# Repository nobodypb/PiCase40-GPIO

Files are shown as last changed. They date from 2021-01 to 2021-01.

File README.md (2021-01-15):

# PiCase40-GPIO

Fixing the GPIO rows order of Cooler Masters Pi Case 40.
KiCAD project for custom header pcb in `PiHeader`.

**NOT FULLY TESTED YET!**

## Guide for fixing with custom made ribbon cable

This is intended as fix **instead** of a custom PCB, so please don't try to combine both.

Overall you *only* need to get two things and stick them together:

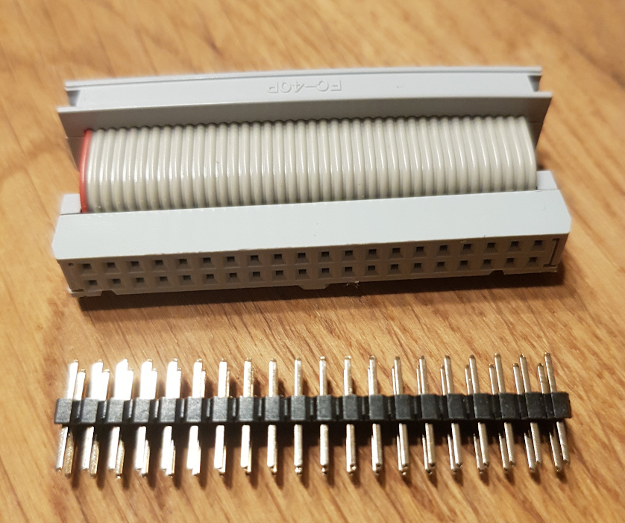
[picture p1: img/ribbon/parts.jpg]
Parts for custom cable fix


On the top you see basically a plain female to female ribbon cable. Such are also often used for the RasPi T-Cobbler.
This specific version I've made myself to arrange the connectors on opposite sides and make it as short as possible, but a longer cable with connectors on the same side will also work.
Just note that the notch on the connector must be facing upwards when it is plugged into the Case40 for it to fit. So get a cable with one notch faced like below.

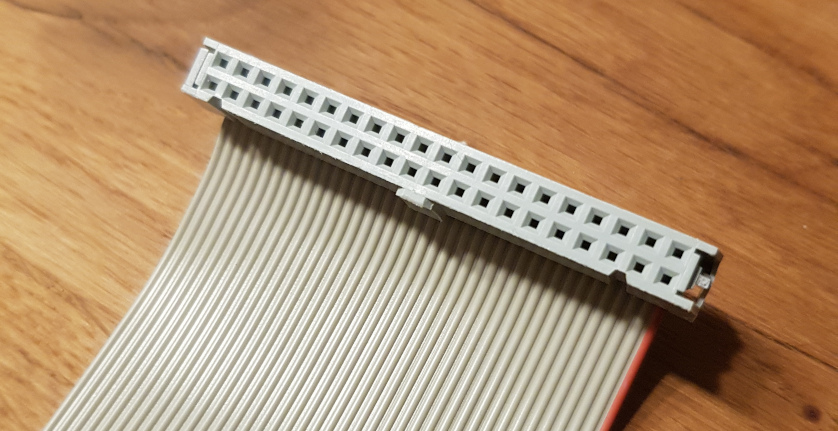
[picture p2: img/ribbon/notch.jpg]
Notch direction


The second part you need is a male to male pinheader with (equally) **long pins on both sides**. Those pins should be at least 5.7mm in length on both sides. Spacing is 2.54mm and ofcourse you need 2x20 pins.
That sounds pretty simple, but as I discovered, it's hard to find and get. If you find distributors for this, please tell me.

A list of possible sources:
* [Aliexpress](https://www.aliexpress.com/item/33021895185.html)
* [Digikey](https://www.digikey.com/product-detail/en/sullins-connector-solutions/PRPC020DABN-RC/S2021EC-20-ND/2775919)
* [Kenable](https://www.kenable.co.uk/en/computer-cables-peripherals/ide-cables/1250-ide-pata-40-pin-40pin-coupler-adapter-male-pins-to-male-pins-001250-5055383412501.html) (also sells on amazon)
* [Schmartboard](https://schmartboard.com/qty-4-2-x-20-male-extra-long-headers-920-0198-01/)

If you fail to get one of those, try your luck on using two single row headers. Like these: [Aliexpress](https://www.aliexpress.com/item/32651418137.html)

After you managed to get those two parts you simply stick them together and one end into the header of your Pi Case40:

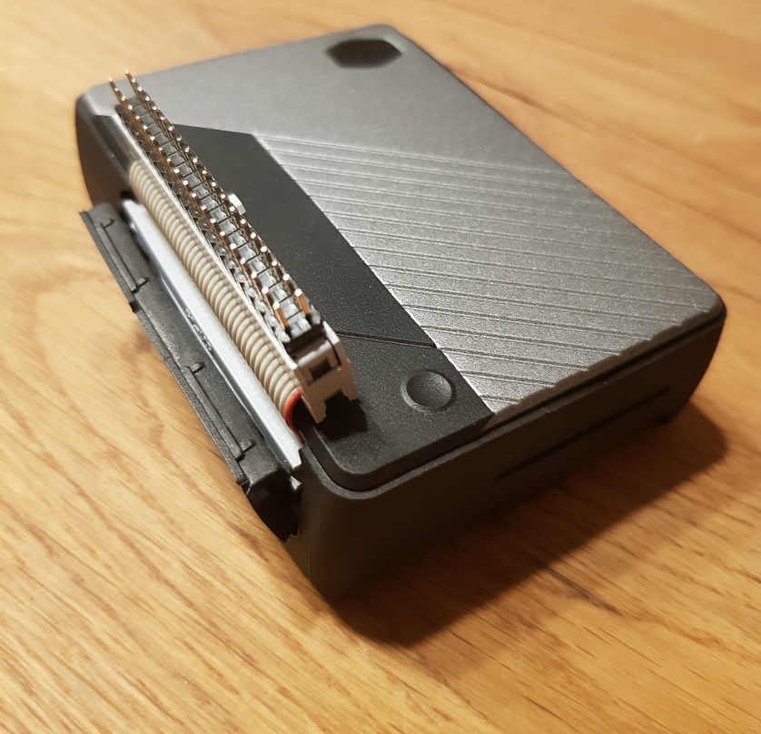
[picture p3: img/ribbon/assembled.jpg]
Assembled ribbon cable fix


Afterwards you can use yours HATs aus usual! Just make sure not to plug in the HAT the wrong way around, especially if your plugs are facing the same direction.

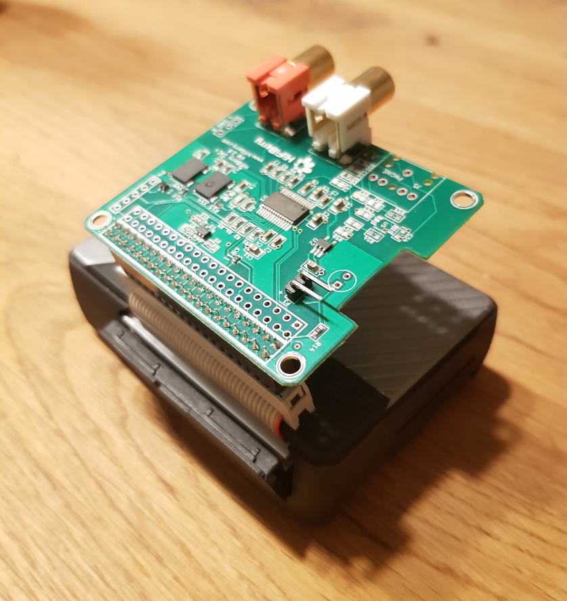
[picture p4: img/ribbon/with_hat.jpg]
Fix with connected HAT


## Quick evening update

I've recieved my ordered PCBs today and wanted to share a quick update:

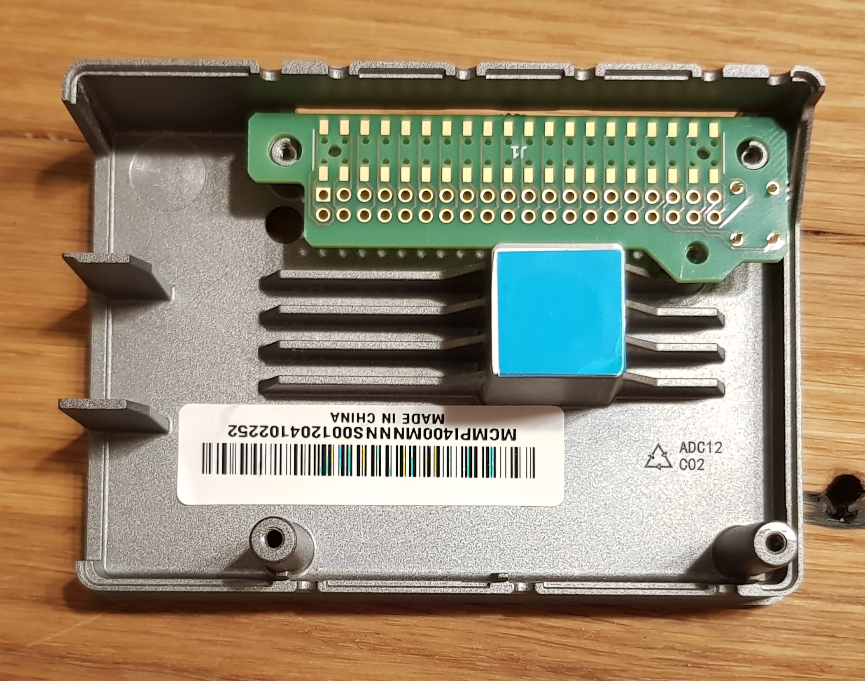
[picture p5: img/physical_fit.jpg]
Topview of PCB in case

As you can see the physical dimensions of the PCB are all correct and fit really well.

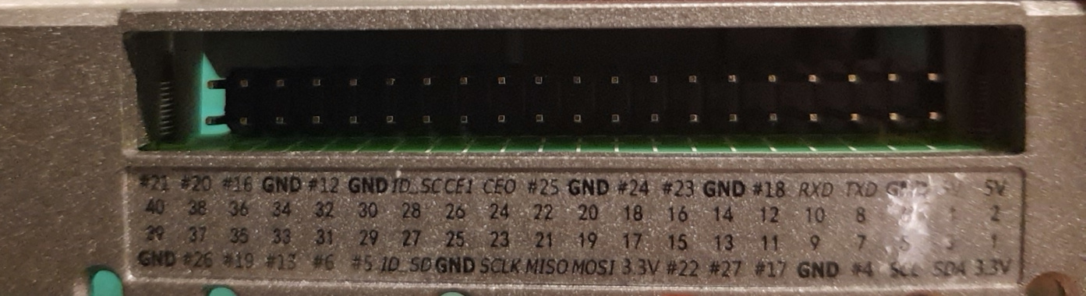
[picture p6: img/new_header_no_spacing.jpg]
Sideview of PCB with header in case

The pin header also is correct, but due to the missing spacing aligned to the bottom of the opening.
I've already successfully tested a small hack to add some spacing that worked very well and got the header to the center.
That is only applicable when assembling by hand though.

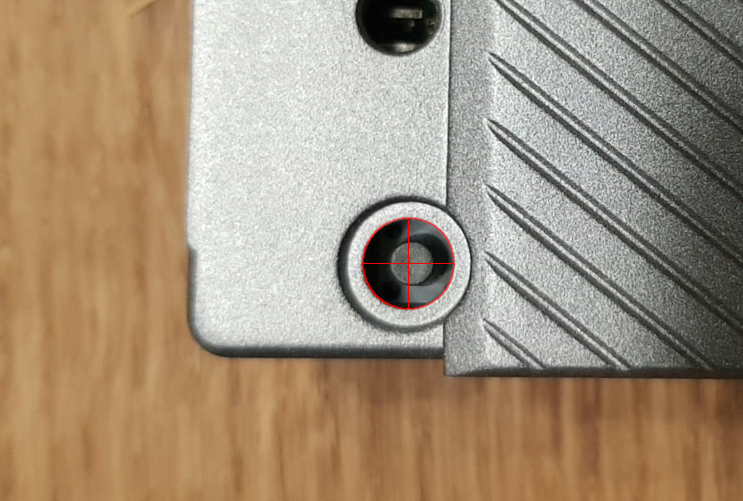
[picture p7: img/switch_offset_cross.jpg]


The button has a small offset to the right, that's something I'll fix in the layout soon. While this isn't affecting functionality there is another problem that does.
Without TPU the button works just fine, but otherwise it's to short to get pressed. That's because I didn't find one with 10.5mm in height, but used 9.6mm. Therefore here is also a spacing hack needed.
Besides that the operation force of the button I used seems to be to low. With TPU I barely get haptic feedback when pressing it. I've used `TL1105GF160Q` so I suggest to try `TL1105GF250Q` or something with an equally high actuation force.

I've soldered one version together and tried the fitting of the RasPi. In X and Y direction, there's no problem. The pin headers fit like a charm and even are easier to pull out then the original due to lower height.
Since I ordered a board with a thickness of 1.6mm for the first test, I still had to test if the cooler was in contact with the SoC. For this I used some plasticine.
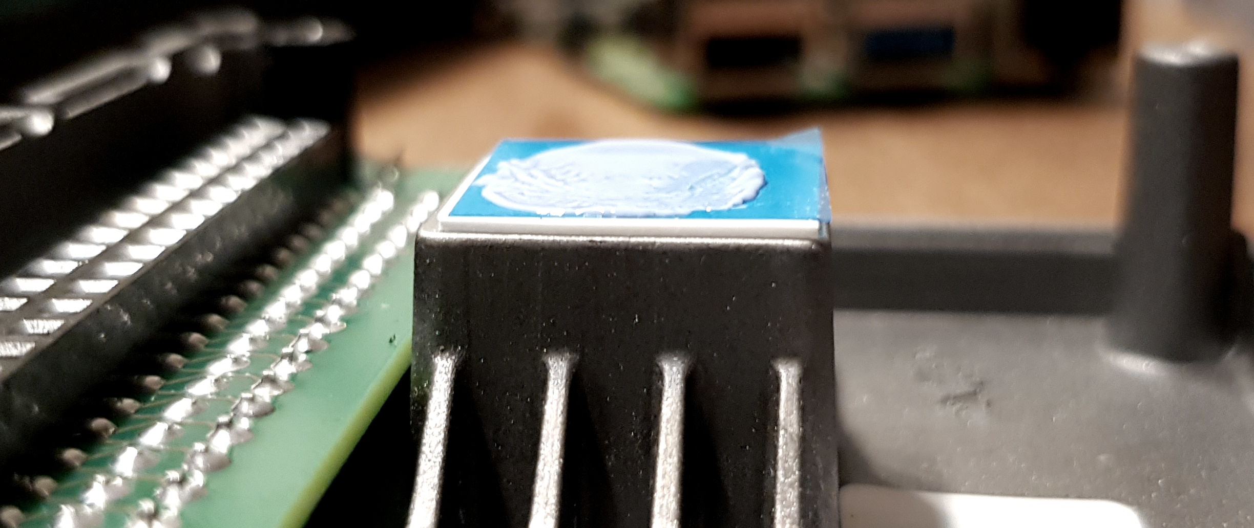
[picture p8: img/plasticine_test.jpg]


As expected, the gap is a bit higher than with the original board, but even with just one thermal pad it might still work. 
To be on the safe side, I used two pads and with those I clearly felt the back pressure. On the left side, I couldn't even tighten the screws strongly to avoid bending the board.
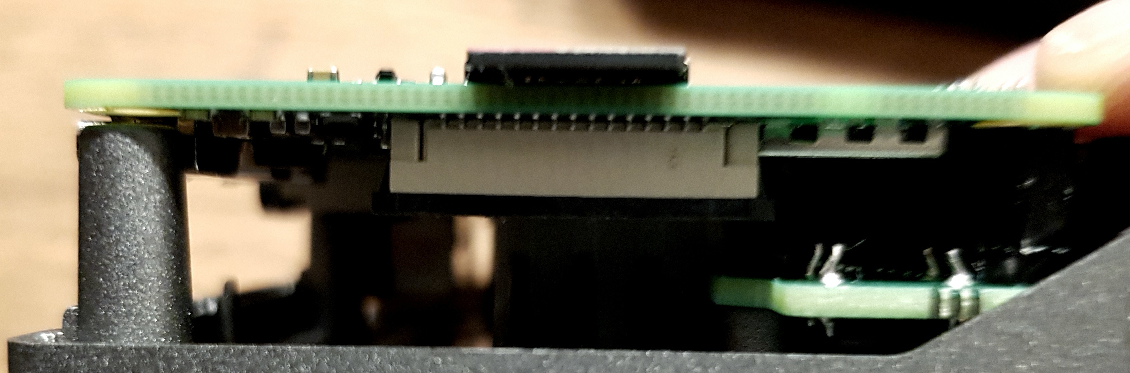
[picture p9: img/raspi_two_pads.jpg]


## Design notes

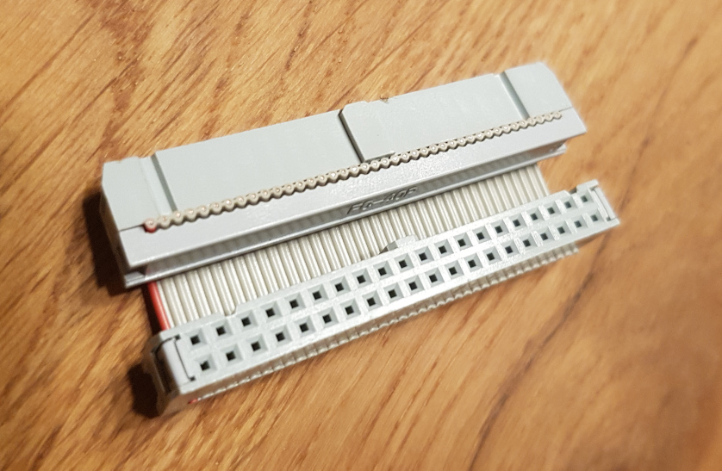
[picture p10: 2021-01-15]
img/ribbon/cable.jpg

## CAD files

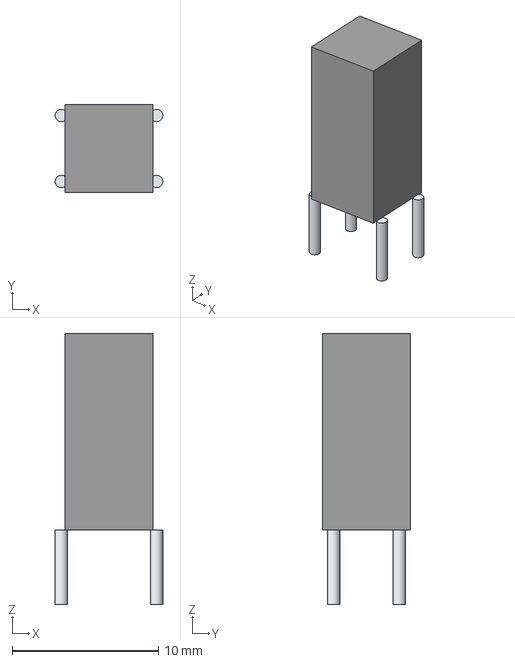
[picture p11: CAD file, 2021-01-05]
PiHeader/shapes3D/TL1105GF160Q.stp
7.35 x 6.00 x 18.5 mm
Leads x 4

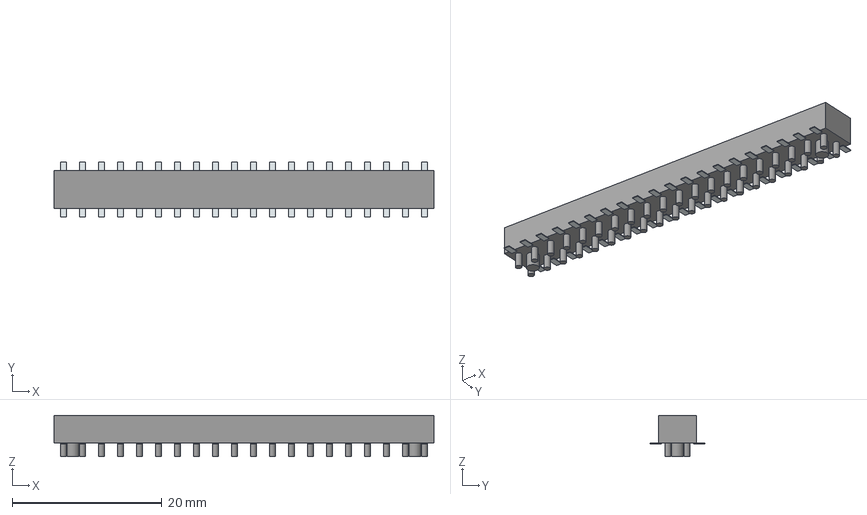
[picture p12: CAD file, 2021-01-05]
PiHeader/shapes3D/M20-7812045.stp
50.8 x 7.40 x 5.50 mm
Pins
Lugs x 42

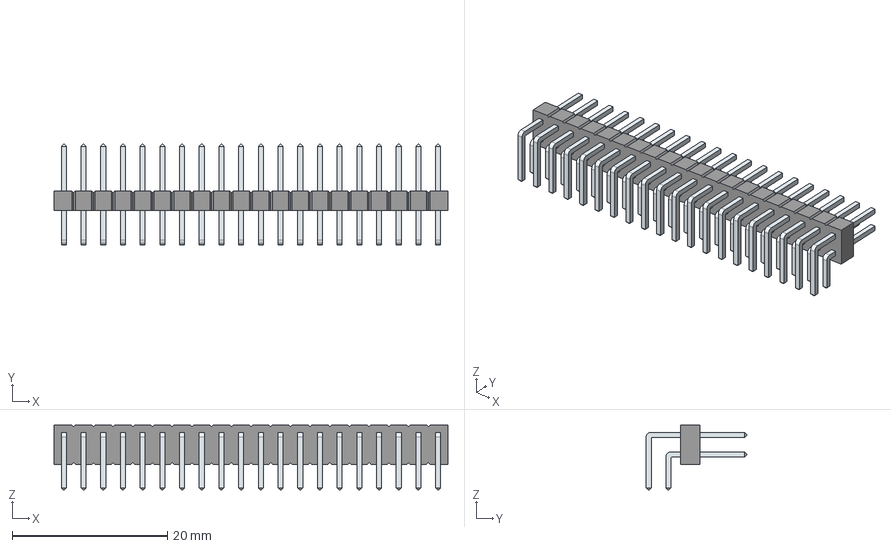
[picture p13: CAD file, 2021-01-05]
PiHeader/shapes3D/10129382-940001BLF.stp
50.8 x 13.0 x 8.38 mm
LeadsArray x 2

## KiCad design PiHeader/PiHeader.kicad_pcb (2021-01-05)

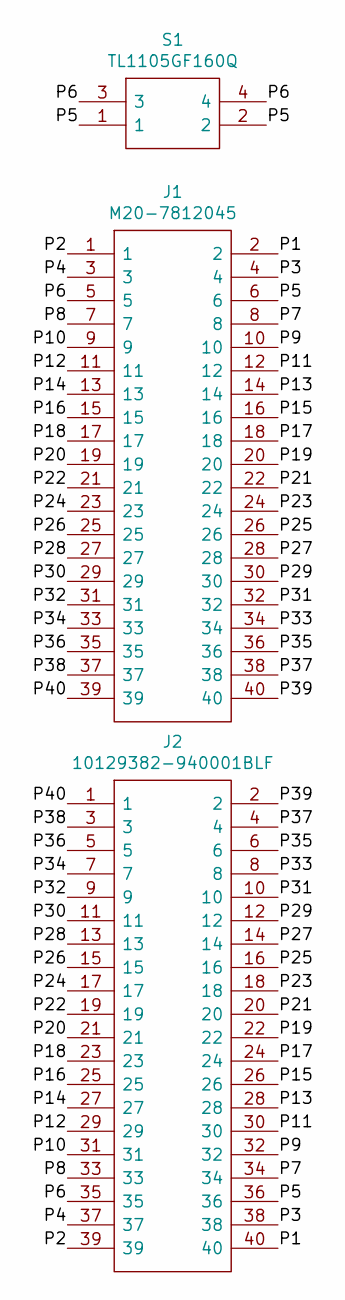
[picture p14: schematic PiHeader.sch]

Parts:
J1: M20-7812045; M207812045; Mouser Part Number 855-M20-7812045
J2: 10129382-940001BLF; HDRRA40W67P254_2X20_5080X254X508P; Manufacturer_Part_Number 10129382-940001BLF; Mouser Part Number 649-1012938294001BLF
S1: TL1105GF160Q; Mouser Part Number 612-TL1105G160Q

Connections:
/P1: J1.2, J2.40
/P2: J1.1, J2.39
/P3: J1.4, J2.38
/P4: J1.3, J2.37
/P5: J1.6, J2.36, S1.1, S1.2
/P6: J1.5, J2.35, S1.3, S1.4
/P7: J1.8, J2.34
/P8: J1.7, J2.33
/P9: J1.10, J2.32
/P10: J1.9, J2.31
/P11: J1.12, J2.30
/P12: J1.11, J2.29
/P13: J1.14, J2.28
/P14: J1.13, J2.27
/P15: J1.16, J2.26
/P16: J1.15, J2.25
/P17: J1.18, J2.24
/P18: J1.17, J2.23
/P19: J1.20, J2.22
/P20: J1.19, J2.21
/P21: J1.22, J2.20
/P22: J1.21, J2.19
/P23: J1.24, J2.18
/P24: J1.23, J2.17
/P25: J1.26, J2.16
/P26: J1.25, J2.15
/P27: J1.28, J2.14
/P28: J1.27, J2.13
/P29: J1.30, J2.12
/P30: J1.29, J2.11
/P31: J1.32, J2.10
/P32: J1.31, J2.9
/P33: J1.34, J2.8
/P34: J1.33, J2.7
/P35: J1.36, J2.6
/P36: J1.35, J2.5
/P37: J1.38, J2.4
/P38: J1.37, J2.3
/P39: J1.40, J2.2
/P40: J1.39, J2.1

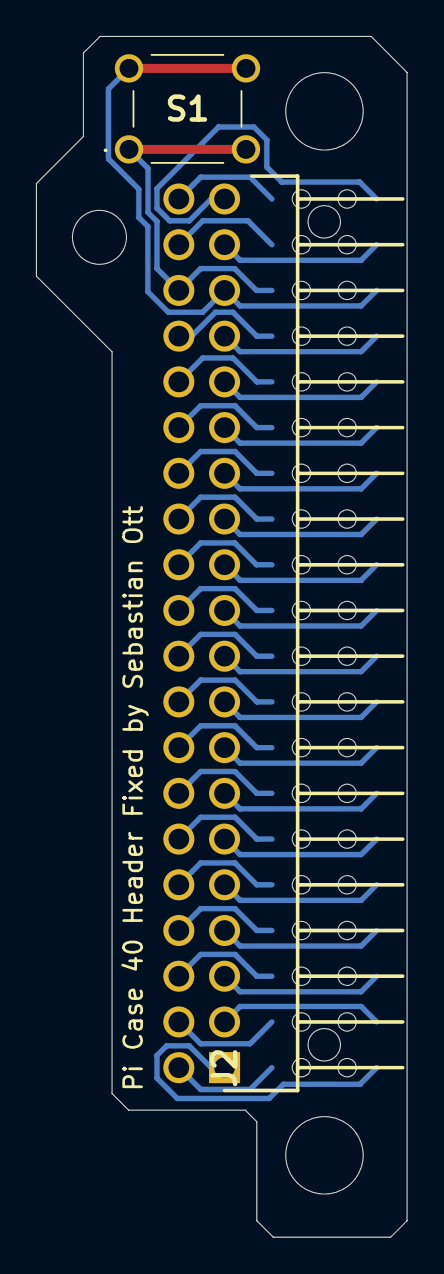
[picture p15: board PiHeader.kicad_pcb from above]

Board: 2 copper layers, 20.6 x 66.7 mm, 3 parts (1 on the bottom side), 40 nets.

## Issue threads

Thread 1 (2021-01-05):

Couple of things

ifohancroft, 2021-01-05:
Hey! Thanks for making this and thanks for sharing with it https://github.com/Pi-Case-40-Community/Pi-Case-40

I get your worry about the PCB height. I am also working on a PCB replacement of my own and that's my worry as well, because of the weird way to have they made the stock one.

I have downloaded your PCB from here and uploaded it to the repo, however, would you mind to make your PCB use a project specific library that contains the footprints, schematic symbols and 3D shapes that the PCB uses, so people don't have to rely on having them, then fork the repo and send a PR, please?

You can check https://github.com/Pi-Case-40-Community/Pi-Case-40/blob/main/README.md for an explanation of what I mean, and my PCB at https://github.com/Pi-Case-40-Community/Pi-Case-40/tree/main/PCB/ifohancroft as an example.

nobodypb, 2021-01-06:
Hello! Thanks for including it that fast. I can't wait to have a look on your PCB project.

Regarding the PCB height I see two possible issues arising. No 1 is the spacing between the male pin header and the PCB itself, which I do not consider a big problem, since they probably only added the 'CON1' PCB for stability and workflow reasons.
What concerns me the most is the absolut offset added to the spacers that hold the raspi which results in added spacing to the cooler. I for myself can easily shorten the spacers to solve this but few people have this opportunity. So when handsoldering the THTs it would likely be the best to simply use a thin PCB.

1. Sorry about that. Haven't worked with KiCAD for a while and forgot it doesn't include the used parts in the project. I've now added project specific librarys to my project. Though I didn't read your naming conventions first, so I need to rename again prior to the PR. Additionally I added the datasheets for the parts I'd use and possible alternatives if those aren't available.

2. For my own batch of PCBs I used Aisler since I really like their service and the possibility to order a package with parts included and share that with others: https://aisler.net/p/LNAQFZOC. However for a potential community based collective order I'd use a cheaper manufacturer for large quantities like PCBWay where you also can choose PCB thickness.

3. I also got somewhat more than 10mm on measuring the switch. However after checking a whole bunch of vendors I coudn't find a single source for such switches. So I decided to use the next closest size I could find, which is the 9.7mm of the `TL1105GF160Q`. The datasheet referenced in the KiCAD part is likely wrong about the total size, since button heights are typically measured from the top of the PCB. To me it looks like a slightly shorter button should work just fine, especially with a thicker PCB, but that's actually one of the things I need to test.

4. I just used the a reasonable width that fitted between the pads of the connectors. Experience shows that the currents are negligible for such short traces. At least when it comes to anything that's possibly connected to a raspi. I may have a look if it's possible to somewhat widen the power paths but without using vias which I tend to avoid on hobby projects, there is simply no sane way to use decisive wider traces. One could argue that I may reduce width for the signal traces to reduce capacity, but I don't see any realworld advantages coming out of that. The principle here is KISS ;)

5. I used to, but right now I have no client installed anymore and especially no BNC setup to stay online. But I may use a webclient to get in touch. On the other hand, shouldn't we keep technical discussions on a platform where everyone can read and comment them?

6. I did not write down my measurements, but modeled them directly into the board outline with small modifications. But I've put a lot of effort in that so you can confidently asume that the resulting outline fits well. There is also enough free space around the PCB for error tolerance. Just take the physical dimensions from my project files. If you want to be on the safe side just wait some days. My PCBs are currently in production and will be shipped soon, so I'll be able to give concrete answers.

Thanks for your questions, they've challenged me to think about some things closer again. Feel free to ask further.

ifohancroft, 2021-01-06:
I feel like the height of the stock female header isn't even enough as if you remember, it doesn't come out exactly in the center of the cutout, but actually more to the bottom of the cutout.

1. Sorry, I hope the rules/conventions are not too strict for the repo. I've re-did them a couple of times, trying to have some consistency and to assure the existance of things that would make it easy to use and navigate but trying to not make them too strict.

2. Thank you! Their price doesn't seem bad for a prototype at all. I was thinking about using First PCB (now renamed to eecart) but I want to redo my footprints according to the specific components I am going to use and they haven't yet updated their website to list the components they tend to keep in-stock.

3. I also couldn't find any exact switches but I can't believe my measurements to the last digit as my current calipers suck. I mean we will be ordering prototypes anyway, so we can change the switches later if needed.

4. I did the same pretty much. Trying to stick to the original design and components, there is really not much wiggle room for track width anyway.

5. Good point about keeping it in a place where anyone can catch up on the convo.

 6. Thank you! I forgot to check that. I want to confirm some of my measurements and figure out others (like the difference between the two edges at the top around the screw hole. I did look at the design and wrote down which measurements are like there are because of what (I mean for example the screw holes, their distance is what it is so it matches with the Raspberry Pi's mount holes, and their size is so the inner screw post goes through them but they lay on the outer part of it) but there are parts of it that are like they are just because that's how they've been designed and I'd like to match the original PCB's footprint.

nobodypb, 2021-01-10:
1. No problem conventions are neccessary imo. It'll just take me some extra time to make my KiCAD project comply when I change it the next time.

2. Well I now think this will need manual assembly nevertheless. - Unless you find the exact buttons and a manufacturer that adds the spacing to the male headers - So it may be easier to buy the parts separately.

4. I think I'll optimize the track width as much as I can, just because I can, once I adjust the button position. ;)

For the remaining points, just check out my updated readme. I recieved my PCBs today and did some tests.

ifohancroft, 2021-01-10:
1. Glad they are not an inconvenience. I should have probably made the README in its current state when creating the repo to avoid having to ask people to re-order their project, but I believe I made the repo in like 6 in the morning. Also, the first version of the README was way more complicated.

P.S. I have added to the README to let people know that if they develop in a repo different than the fork of the one I've made, that it's probably a good idea to add their repo's url.

Please make sure to check where I have added your repo URL and let me know if it's ok with it being there and so you know where it is, in-order to not override it on accident when updating your repo there.

Also, any ideas for changes to the repo structure or anything, let me know.

I will add you to the org in a minute, so you can push directly instead of having to send PRs and wait for me to accept them.

I am not sure about this (whether it will work or how it can be done) so let me know your thoughts, but it got me thinking, if people decide to follow the recommended structure in their original repos, perhaps we can utilize git's submodules to link to the original repos directly, instead of having a copy? Although, I am not sure how the username part will work, otherwize I think it's really easy to just create a submodule under the PCB folder that will link to your repo for example.

2. I have been thinking about trying manual assembly, but with the components being so close together, I am afraid I will burn something or the other :D (Like I did on the original case's PCB when trying to desolder the female header and burned its housing :D ).

I was wondering about that (manufacturer adding the male header spacing: Are you aware of a way where we can separately make the spacer pcb as a footprint and then include it in the main pcb's files? I mean is there a way to automate this so from the files it's clear the manufacturer needs to print the PCB and put them together?

3. I have adjusted some of my PCB and parts positions according to measurements from your PCB as well as removing all the components from the stock PCB and measuring again (I think I got it down to some nice round distances) but I need to test and I also reached the conclusion that around 12mil traces should be good. I mean I have tried researching the power through the Pi and in theory a lot thinner traces should be fine as well, but in some cases if you decide to power the Pi through the GPIO you are bypassing the fuse and you can pass a lot more electricity so 12mil may not be enough, but working with a fixed design, I feel like this is the best we can do. When you optimize then, please let me know how you've reached the decisions and sizes (lenght and thickness/width) that you did.

I have just checked your updated README. First - Good job! It looks very well done!
I have a couple of questions:

1. What is TPU? You mentioned it in regards to the button and it sounds familiar but I can't remember atm.
2. Did you order just the PCB being printed without assembly?
3. I am not sure I understand how the GPIO PCB is affecting/can affect whether the Raspberry Pi can touch the radiator?
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
ifohancroft, 2021-01-16:
Btw, the other day I realized I had a distance mistake in the PCB that would prevent the Pi from fitting because I didn't leave enough space for its PoE header, but I have already ordered PCBs to be printed :D I should order a fixed batch soon.

Btw did you have a chance to check the above messages/comments?

ifohancroft, 2021-01-27:
By the way, I see you have put holes in the middle of the SMD Female Header Socket Footprint. Why is that? Is there any practical reason for it or did the footprint you had just have them?

ifohancroft, 2021-02-04:
When you have time to check all of the above and reply, I'd like your opinion on something more regarding including the repos as submodules

ifohancroft, 2021-02-04:
Since I have edited the previous 2 comments a couple of times, deleted some newer ones that have later been included in the previous ones, and I don't know if that triggers a notifications, or perhaps you have already read the previous comment, before it was edited, this comment here is just to let you know that the previous two comments are new, and to let you know there is new activity on this issue.

ifohancroft, 2021-02-13:
P.S. I have updated the repo and added both our PCBs as submodules, as well as mentioned in the README how to clone to get all the latest submodules, warned about browsing and included info on how to stay up-to-date with the modules.
Feel free to delete your fork as you no longer need to send a PR with your repo included.

Let me know when you are here, I will send you an invite to the org, so you can push to the repo and things like that.

I just need to add the new contributing guide.

P.S. Would you mind renaming your branch from master to main? Just let me know if/when you do that so I can update the submodule to track the new branch name.

ifohancroft, 2021-03-22:
Hey! You haven't been active on GitHub in a while now. Are you alright? Is everything ok?

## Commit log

2021-01-05 Added KiCAD project
    [PiHeader.kicad_pcb, PiHeader.sch]
2021-01-05 Included parts library with 3dmodels
    [10129382-940001BLF.stp, M20-7812045.stp, PiHeader.kicad_pcb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]
2021-01-10 Recieved PCBs. Quick Update
2021-01-15 Added fix with custom ribbon cable
